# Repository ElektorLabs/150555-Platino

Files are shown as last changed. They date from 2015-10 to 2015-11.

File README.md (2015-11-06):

# 150555-Platino
Arduino compatible universal AVR board for 28-pin and 40-pin ATmega devices.

Platino is a board that address the ever returning problem of adding a user interface to a project. With 
Platino this is solved so that you can concentrate on your application instead of fiddling with low-level
drivers for user interfacing.

To achieve this Platino features footprints for pushbuttons, rotary encoders, a buzzer, an (RGB) LED, and an
LCD. Pushbuttons and rotary encoders have a flexible layout allowing a user interface adapted to the applications.
Platino supports 2 lines by 16 characters (2x16), 4x16 and 4x20 LCDs.

An Arduino library/core is available that contains drivers for all the peripherals, making programming easy.
Don't worry about debouncing pushbuttons, controlling LCDs or reading rotary encoders, the library handles it all
for you.

For even more flexibility Platino has solder jumpers to configure the board, allowing peripherals to be connected
to different ports.

Platino supports the following MCUs:
- ATmega8
- ATmega16
- ATmega32
- ATmega48 (not supported in Arduino IDE)
- ATmega88
- ATmega164
- ATmega168
- ATmega324
- ATmega328
- ATmega644
- ATmega1284

Arduino compatible bootloaders for all supported processors (except ATmega48) are available too.

For easy installation Platino is contained in a Board Package for the Arduino IDE, see https://github.com/ElektorLabs/Arduino

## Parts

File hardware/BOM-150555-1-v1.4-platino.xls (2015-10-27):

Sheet: BOM
BOM::150555::PLATINO::v1.4
Description | Manufacturer | Reference | Footprint | Designation | Qnt | Farnell | Digikey | RS
Resistor (5%, 0.25 W) |  |  |  |  | 13
47 Ω | Multicomp | MCF 0.25W 47R | ELPP-70-100 | R2, R3 | 2 | 9339523
470 Ω | Multicomp | MCF 0.25W 470R | ELPP-70-100 | R1, R8, R9 | 3 | 9339531
4.7 kΩ | Multicomp | MCF 0.25W 4K7 | ELPP-70-100 | R11 | 1 | 9339540
10 kΩ | Multicomp | MCF 0.25W 10K | ELPP-70-100 | R4, R5, R6, R7, R10, R12 | 6 | 9339060
Trimmer 10 kΩ, horizontal | TE Connectivity / Citec | CB10LV103M | ELPP-TRIMMER-CB10-H | P1 | 1 | 1227569
Capacitor |  |  |  |  | 7
22 pF, C0G, 50 V, 2.5 mm | Multicomp | MCCHU5220J5 | ELPP-CNP-250 | C1, C2 | 2 | 9411674
10 nF X7R, 100 V, 2.54 mm | Multicomp | MCRR50103X7RK0100 | ELPP-CNP-254 | C4 | 1 | 1216435
100 nF, Z5U, 50 V, 2.54 or 5.08 mm | Multicomp | MCRR50104Z5UM0050 | ELPP-CNP-508 | C3, C5, C6, C10 | 4 | 1216440
1 uF, 50 V, 2.5mm | Multicomp | NP35V105M5X11 | ELPP-CP-200-500 | C7, C8 | 2 | 9451358
10 uF, 50 V, 2.5 mm | Multicomp | NP35V106M5X11 | ELPP-CP-200-500 | C9 | 1 | 9451382
Inductor / Self |  |  |  |  | 1
10 µH | Bourns | 78F100J-RC | ELPP-L-70-100 | L1 | 1 | 1180270
Semiconductor |  |  |  |  | 6
1N5817 | Vishay | 1N5817 | ELPP-DO-41 | D2, D3 | 2 | 9801197
LED RGB, 5 mm | Kingbright | L-154A4SURKQBDZGW | LED RGB 5 mm | LED1 | 1 | 2290374
BC547C, 45 V, 100 mA, 500 mW, hfe=400 | ON Semiconductor | BC547CG | ELPP-TO-92 | T1 | 1 | 2101811
MC7805, 5 V, 1 A | ON Semiconductor | MC7805CTG | ELPP-TO-220-x | IC3 | 1 | 9666095
MCP1700-3302E/TO, LDO, 3.3 V, 0.25 A | Microchip | MCP1700-3302E/TO | ELPP-TO-92 | IC4 | 1 | 1296588
Misc.
IC socket DIP40 | Multicomp | 2227MC-40-06-05-F1 | ELPP-IC-SOCKET | IC1 | 1 | 1103855
IC socket DIP28, 7.62 mm (narrow) | Multicomp | 2227MC-28-03-05-F1 | ELPP-IC-SOCKET | IC2 | 1 | 1103850
16 MHz, 18 pF | Raltron | AS-16.000-18 | ELPP-HC49 | X1 | 1 | 1611761
Buzzer 12 mm | Pro Signal | ABT-410-RC | ELPP-BUZZER-12MM | BUZ1 | 1 | 1022402
Push button | Multimec | 3FTL6 | through-hole | S1, S2, S3, S4 | 4 | 1132885
Rotary encoder | Alps | EC12E2424407 | through-hole | SW1, SW2 | 2 | 1520813
header socket 10 pin, 0,1" pitch vertical | Fisher Elektronik | BL1.10Z | ELPP-SIL-F-10-WAY | K1 | 1 | 9728856
header male 6 pin, 0.1" pitch vertical | Fisher Elektronik | SL1.025.6Z | ELPP-SIL-M-6-WAY-90DEG | K2 | 1
header male 2x3 pin, 0.1" pitch vertical | Fisher Elektronik | SL2.025.6Z | ELPP-DIL-M-6-WAY-V | K3 | 1 | 9729070
header socket 8 pin, 0,1" pitch vertical | Fisher Elektronik | BL1.8Z | ELPP-SIL-F-8-WAY | K4, K5 | 2 | 9728856
header socket 6 pin, 0,1" pitch vertical | Fisher Elektronik | BL1.6Z | ELPP-SIL-F-6-WAY | K6, K7 | 2 | 9728856
header male 3 pin, 0.1" pitch vertical | Fisher Elektronik | SL1.025.3Z | ELPP-SIL-M-3-WAY | K8 | 1 | 9729038
header socket 16 pin, 0,1" pitch vertical | Fisher Elektronik | BL1.16Z | ELPP-SIL-F-16-WAY | K9 | 1 | 9728856
Terminal block 3.5 mm, 2-way, 250 V | TE Connectivity | 1776275-2 | ELPP-TB-350-2 | K12 | 1 | 1098611
 |  |  |  | K10, K11
LCD 2x16
LCD 4x20

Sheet: history
DOCUMENT HISTORY
Date | Rev. | Author | Description

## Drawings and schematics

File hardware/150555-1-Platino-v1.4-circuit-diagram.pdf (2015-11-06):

## CONFIGURE SOLDER JUMPERS FIRST

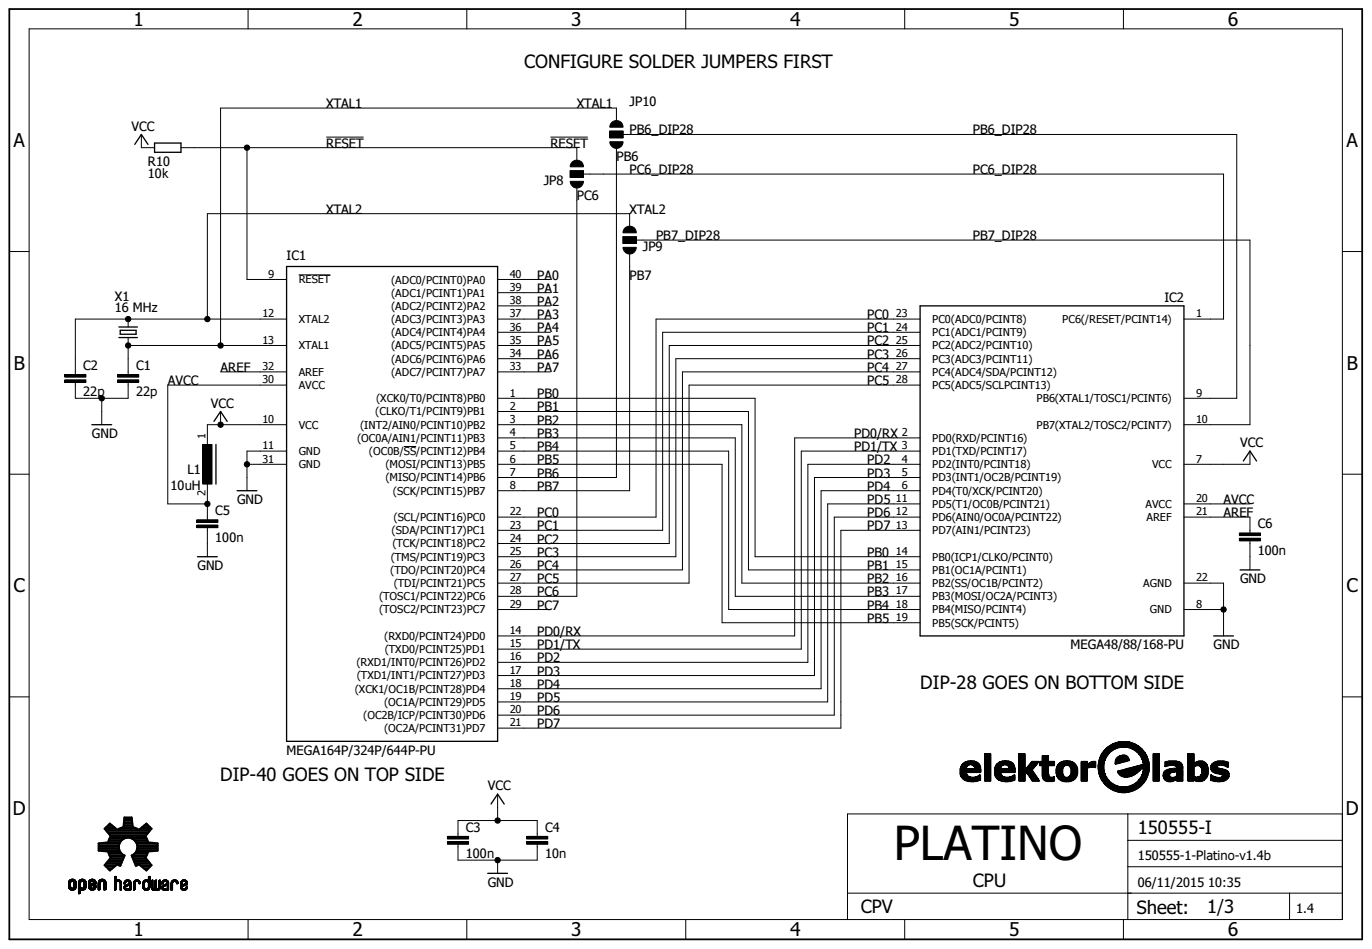
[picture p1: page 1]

DIP-28 GOES ON BOTTOM SIDE

DIP-40 GOES ON TOP SIDE

## CONFIGURE SOLDER JUMPERS FIRST

## Ex = Encoder x LCD_20X4

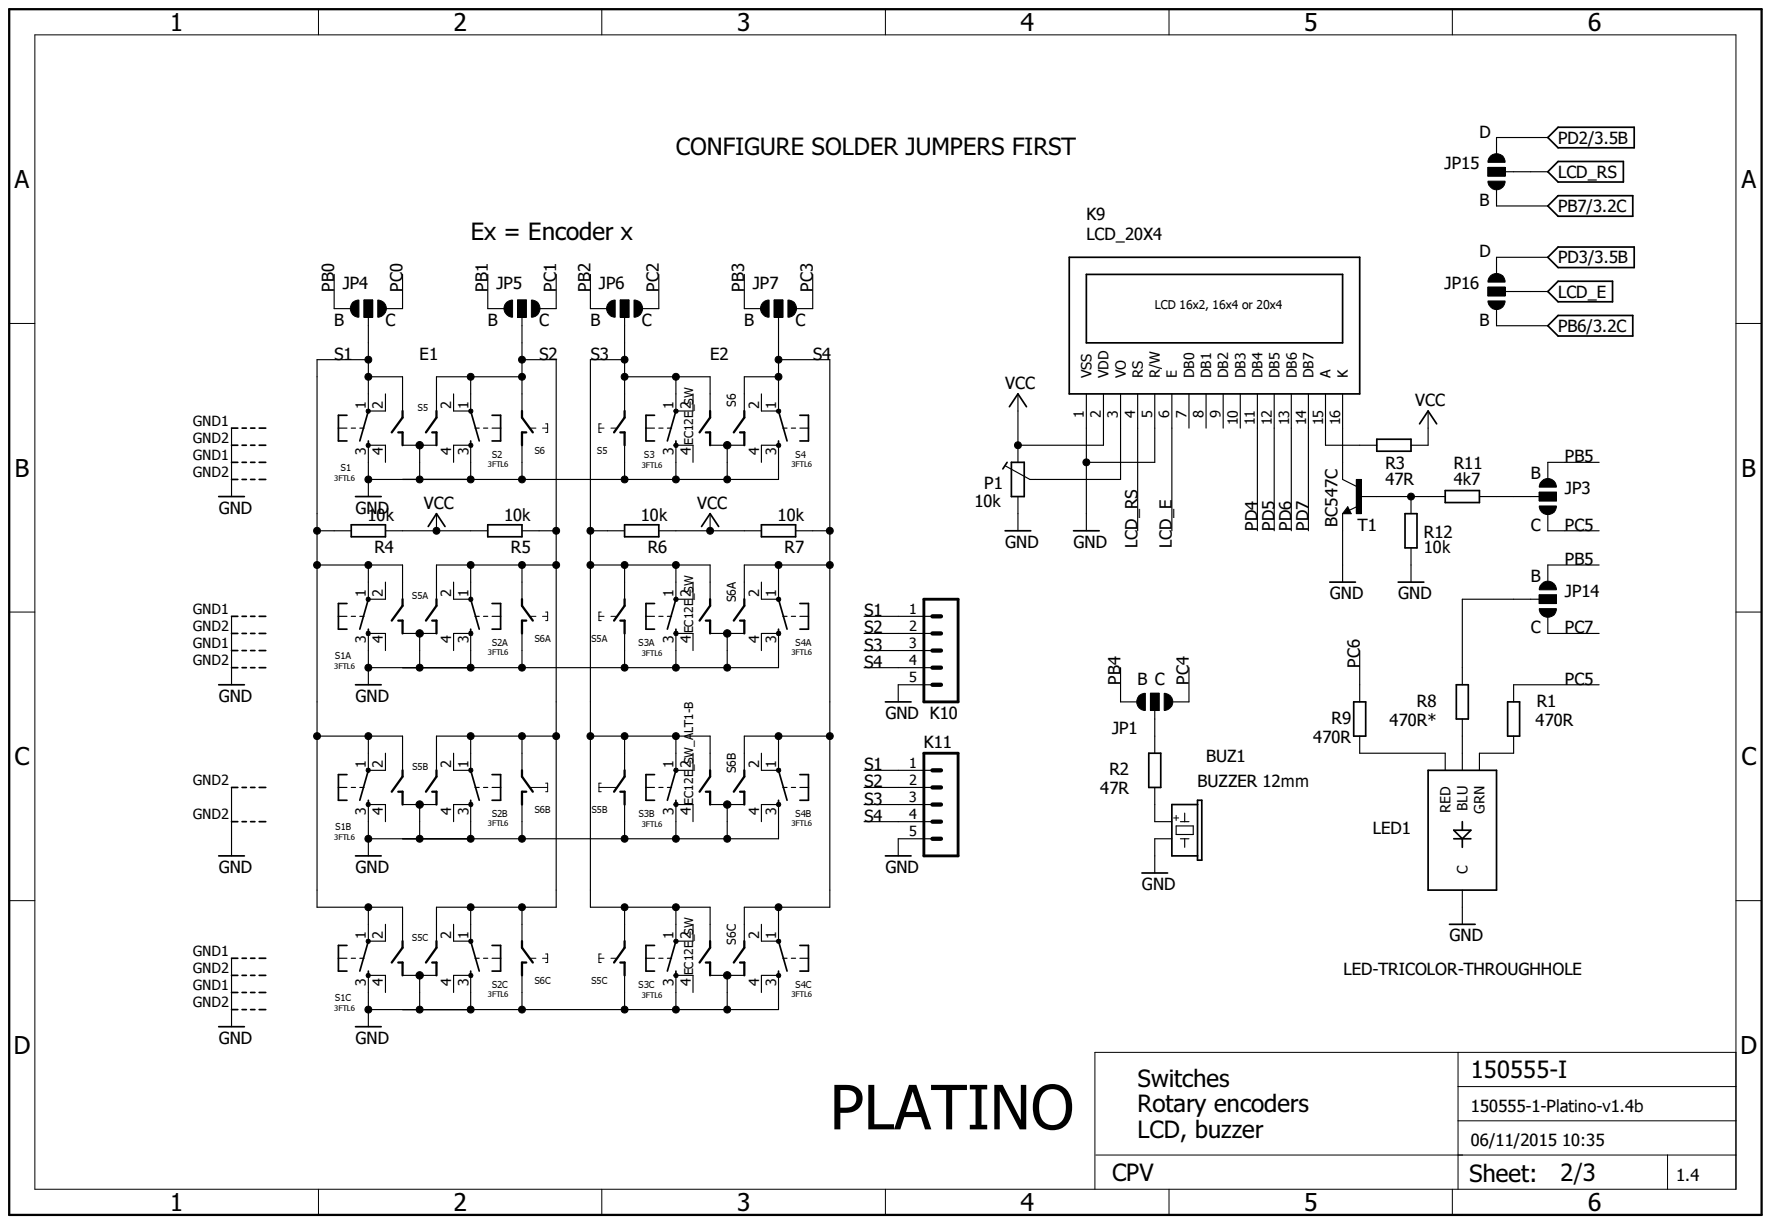
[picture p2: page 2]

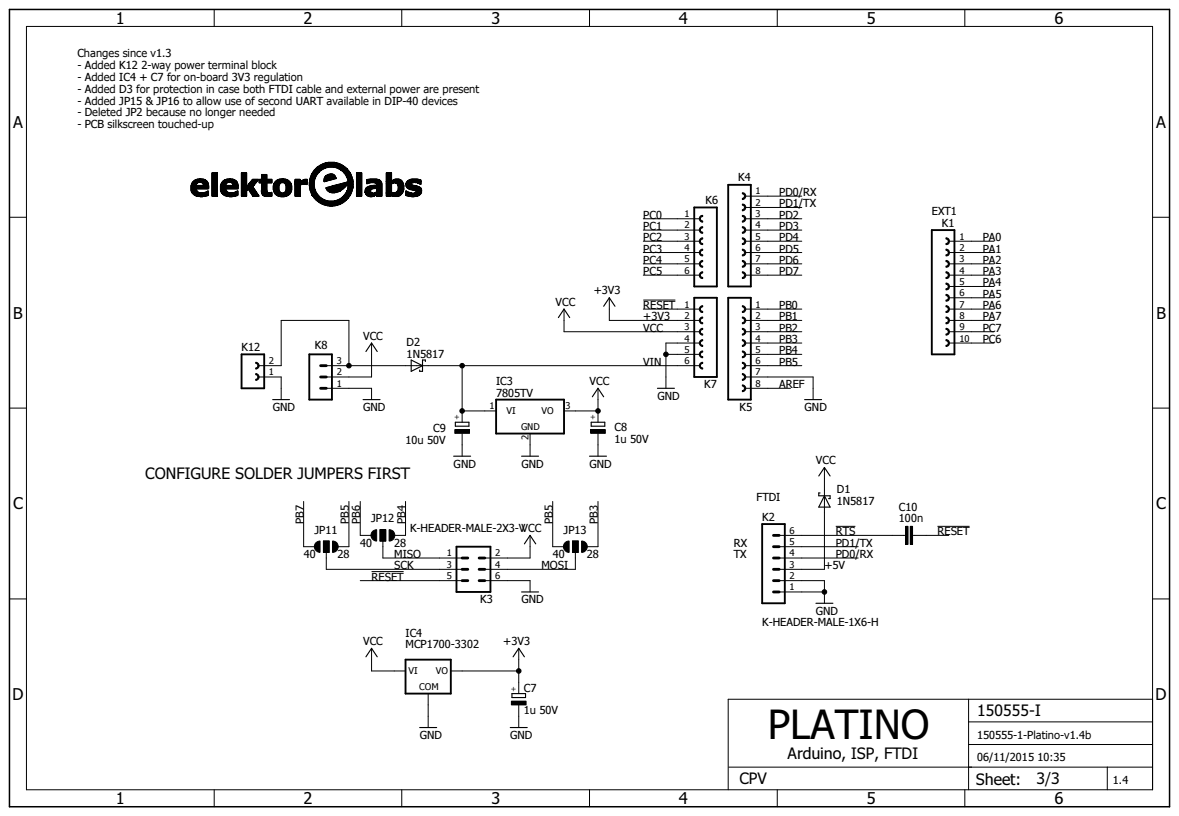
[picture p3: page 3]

Changes since v1.3
- Added K12 2-way power terminal block
- Added IC4 + C7 for on-board 3V3 regulation
- Added D3 for protection in case both FTDI cable and external power are present
- Added JP15 & JP16 to allow use of second UART available in DIP-40 devices
- Deleted JP2 because no longer needed
- PCB silkscreen touched-up

CONFIGURE SOLDER JUMPERS FIRST

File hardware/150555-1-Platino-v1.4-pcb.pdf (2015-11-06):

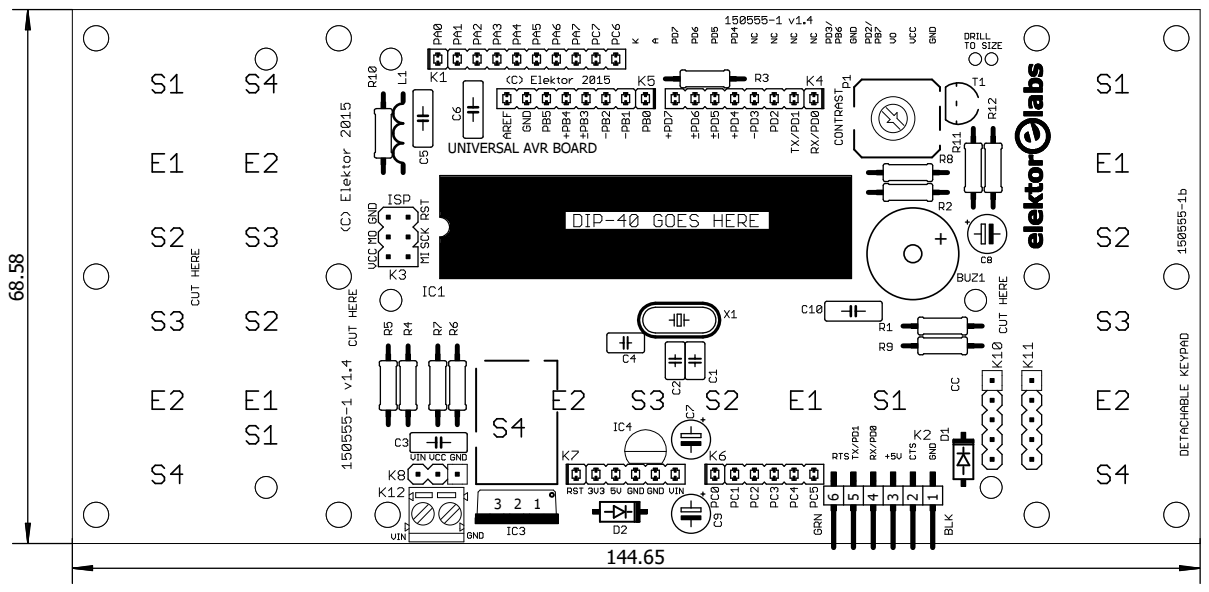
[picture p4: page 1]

UNIVERSAL AVR BOARD

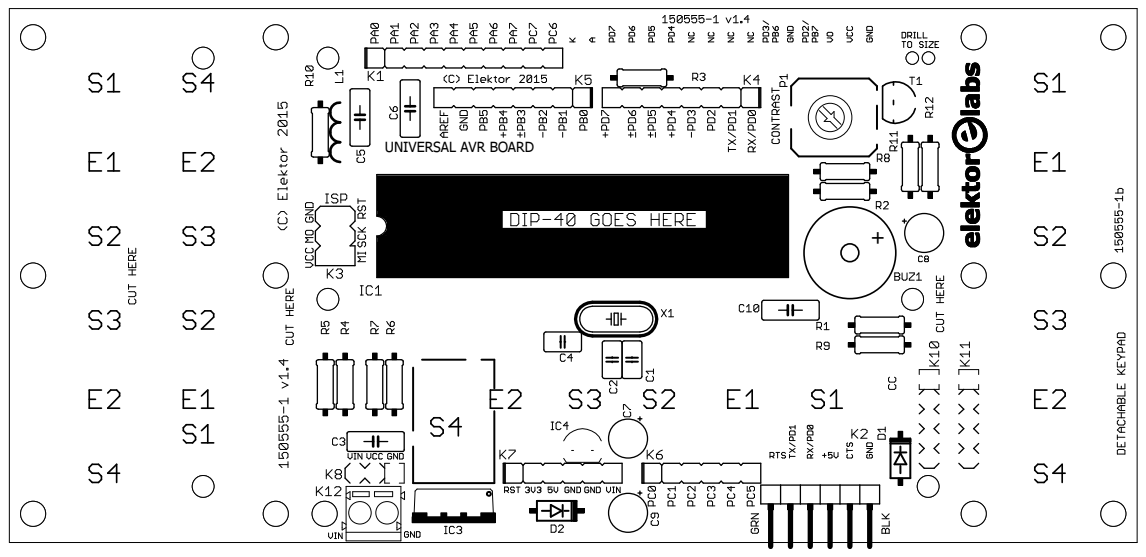
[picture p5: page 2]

UNIVERSAL AVR BOARD

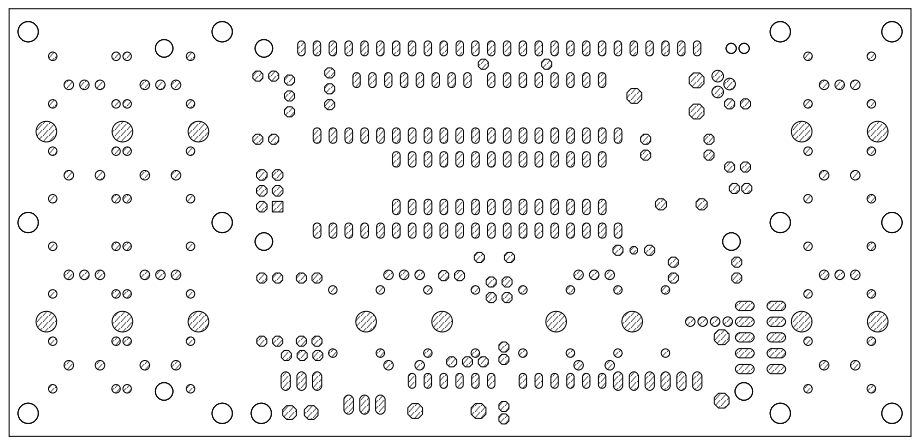
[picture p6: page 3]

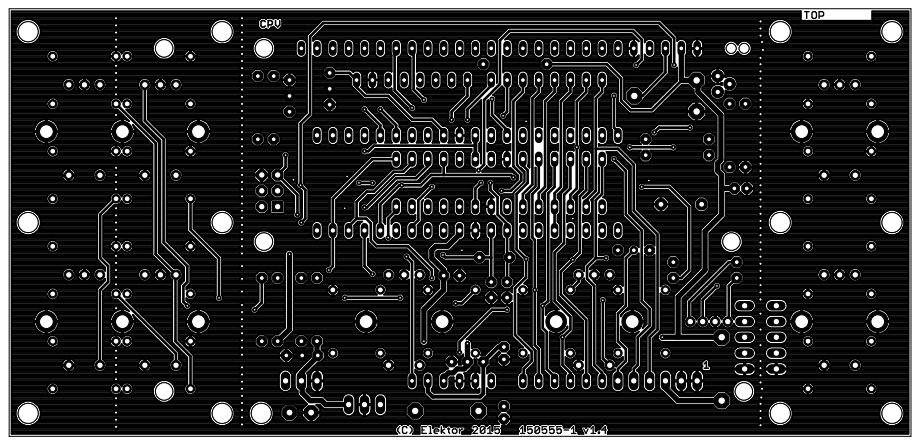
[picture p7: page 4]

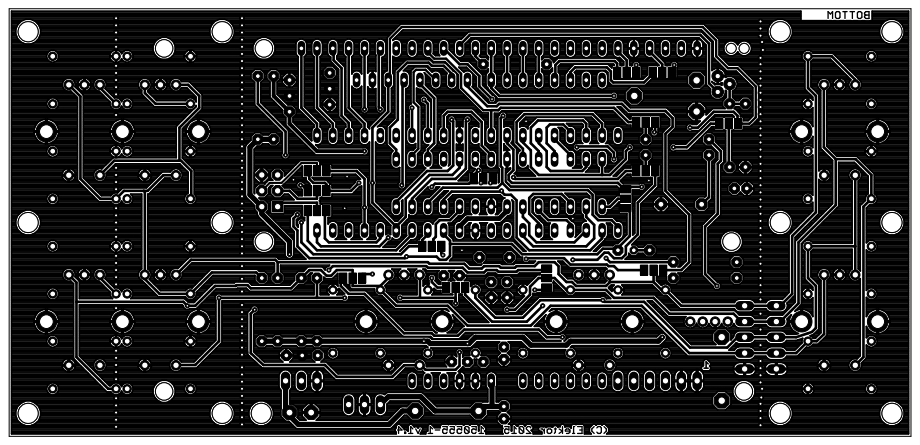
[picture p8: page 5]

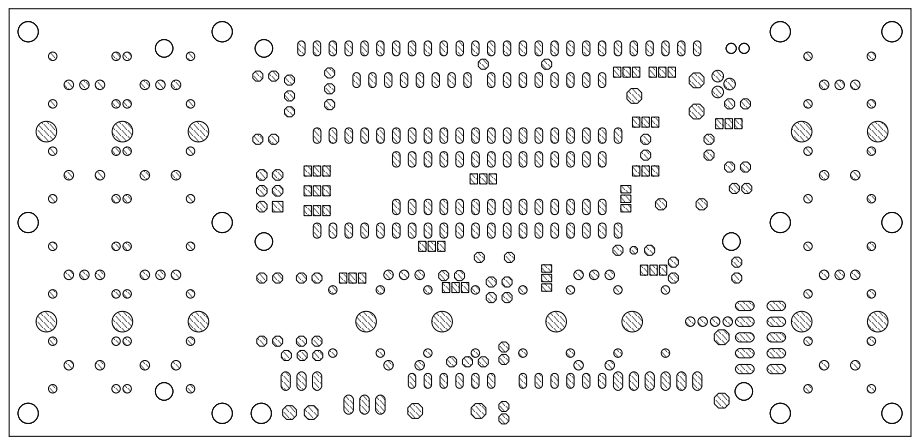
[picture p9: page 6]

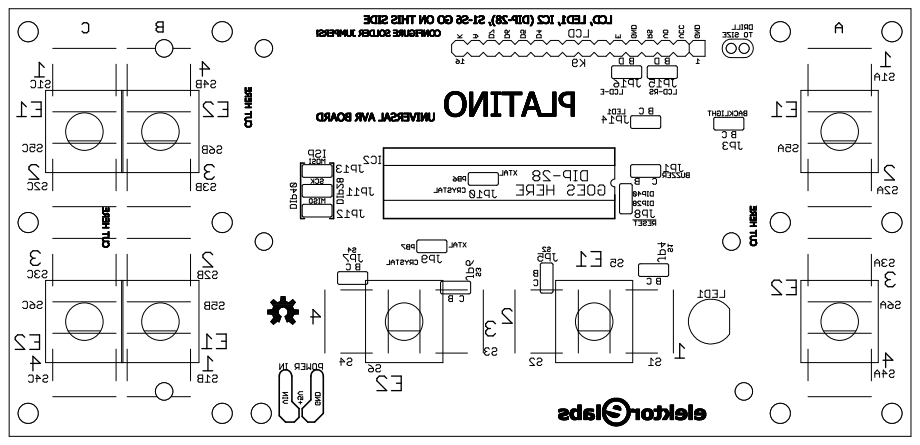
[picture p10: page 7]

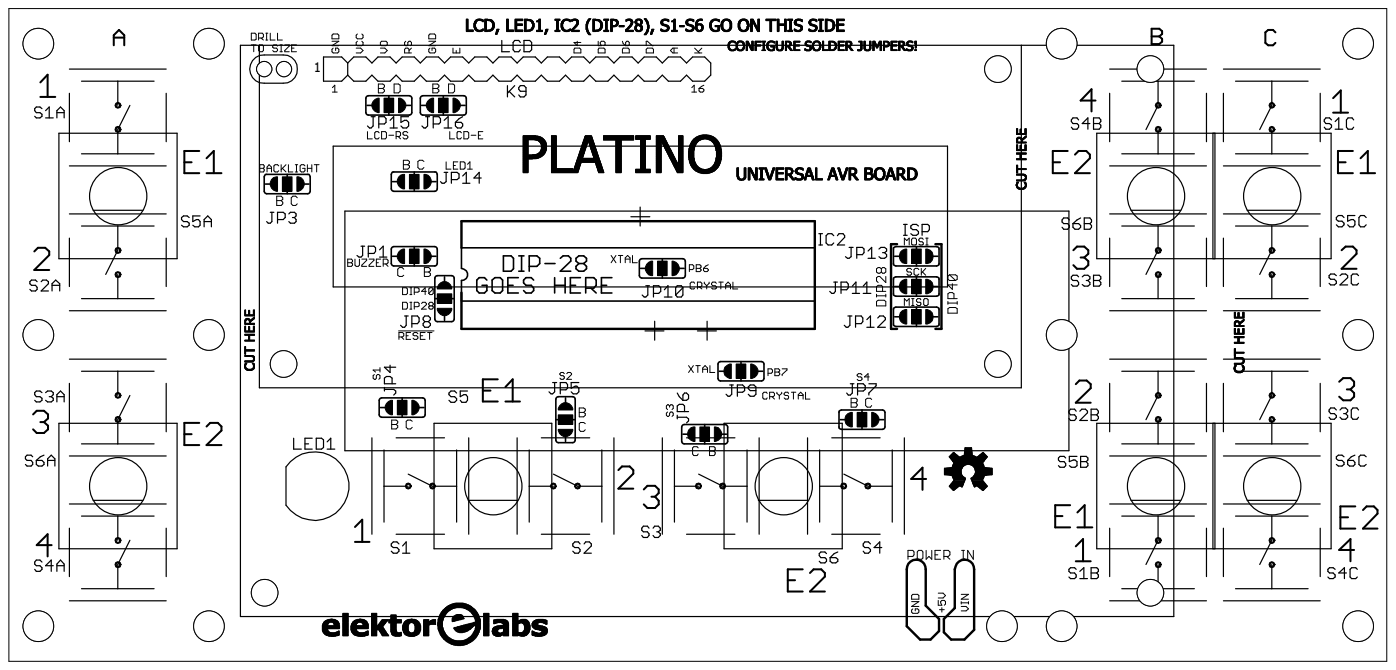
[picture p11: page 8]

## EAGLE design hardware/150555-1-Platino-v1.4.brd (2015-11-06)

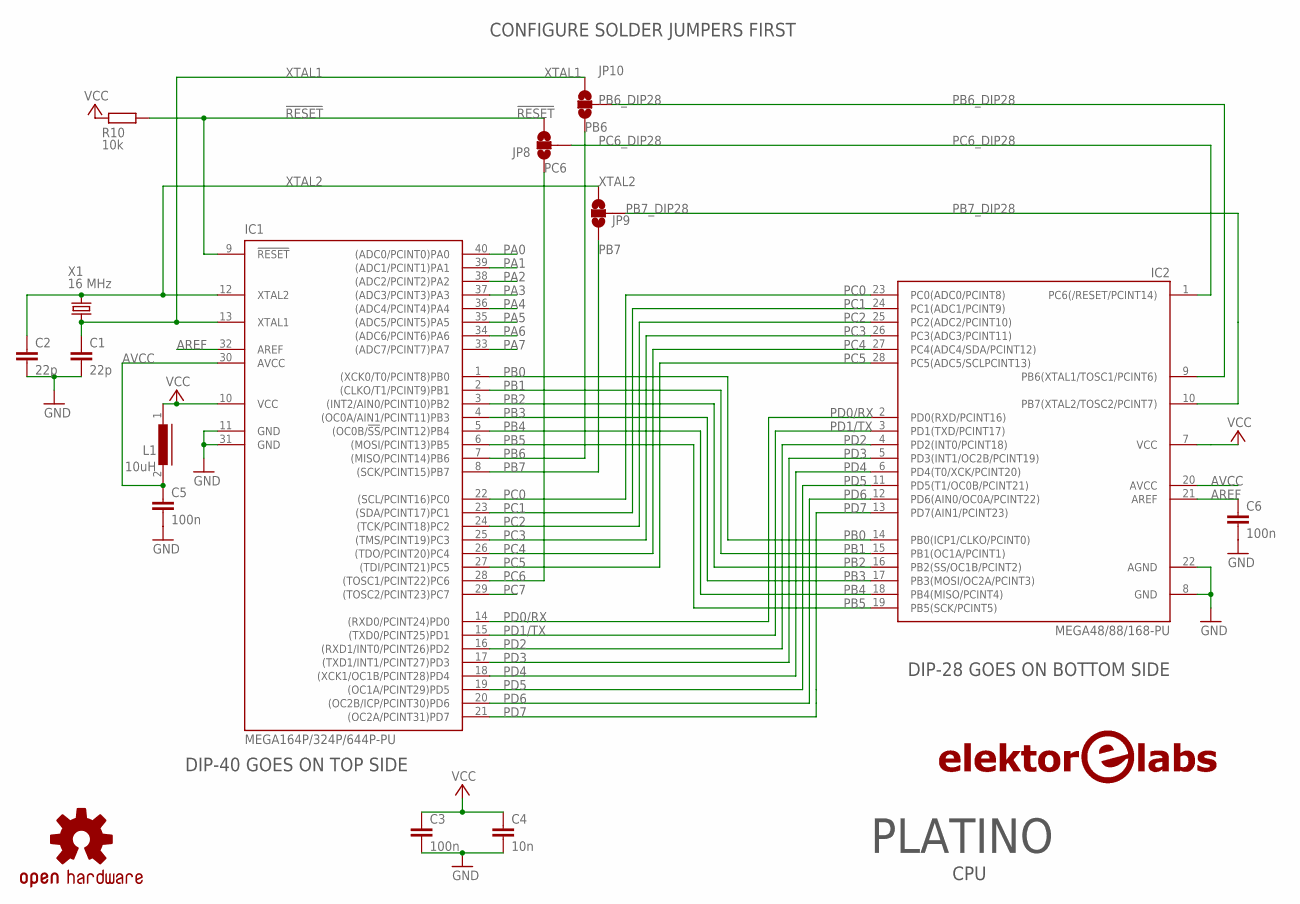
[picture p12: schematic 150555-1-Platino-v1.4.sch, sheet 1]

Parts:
C1, C2: 22p; ELPP-CNP-250
C3, C5, C6: 100n; ELPP-CNP-508
C4: 10n; ELPP-CNP-254
IC1: MEGA164P/324P/644P-PU; DIL40
IC2: MEGA48/88/168-PU; DIL28-3
JP8, JP9, JP10: SOLDERJUMPER_2WAYT; SJ_2
L1: 10uH; ELPP-L-0207-1000
LOGO2: LOGO-ELEKTOR-LABS-25MM; EPP-LOGO-ELEKTOR-LABS-25MM
R10: 10k; ELPP-R-0207-1000
U$2: OSHW-LOGOM; OSHW-LOGO-M
X1: 16 MHz; ELPP-HC49

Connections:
!RESET: IC1.9 (!RESET), JP8.3, R10.1; also elsewhere on the board
AREF: C6.1, IC1.32 (AREF), IC2.21 (AREF); also elsewhere on the board
AVCC: C5.1, IC1.30 (AVCC), IC2.20 (AVCC), L1.2
GND: C1.2, C2.2, C3.2, C4.2, C5.2, C6.2, IC1.11 (GND), IC1.31 (GND), IC2.8 (GND), IC2.22 (AGND); also elsewhere on the board
PA0: IC1.40 ((ADC0/PCINT0)PA0); also elsewhere on the board
PA1: IC1.39 ((ADC1/PCINT1)PA1); also elsewhere on the board
PA2: IC1.38 ((ADC2/PCINT2)PA2); also elsewhere on the board
PA3: IC1.37 ((ADC3/PCINT3)PA3); also elsewhere on the board
PA4: IC1.36 ((ADC4/PCINT4)PA4); also elsewhere on the board
PA5: IC1.35 ((ADC5/PCINT5)PA5); also elsewhere on the board
PA6: IC1.34 ((ADC6/PCINT6)PA6); also elsewhere on the board
PA7: IC1.33 ((ADC7/PCINT7)PA7); also elsewhere on the board
PB0: IC1.1 ((XCK0/T0/PCINT8)PB0), IC2.14 (PB0(ICP1/CLKO/PCINT0)); also elsewhere on the board
PB1: IC1.2 ((CLKO/T1/PCINT9)PB1), IC2.15 (PB1(OC1A/PCINT1)); also elsewhere on the board
PB2: IC1.3 ((INT2/AIN0/PCINT10)PB2), IC2.16 (PB2(SS/OC1B/PCINT2)); also elsewhere on the board
PB3: IC1.4 ((OC0A/AIN1/PCINT11)PB3), IC2.17 (PB3(MOSI/OC2A/PCINT3)); also elsewhere on the board
PB4: IC1.5 ((OC0B/!SS!/PCINT12)PB4), IC2.18 (PB4(MISO/PCINT4)); also elsewhere on the board
PB5: IC1.6 ((MOSI/PCINT13)PB5), IC2.19 (PB5(SCK/PCINT5)); also elsewhere on the board
PB6: IC1.7 ((MISO/PCINT14)PB6), JP10.1; also elsewhere on the board
PB6_DIP28: IC2.9 (PB6(XTAL1/TOSC1/PCINT6)), JP10.2
PB7: IC1.8 ((SCK/PCINT15)PB7), JP9.1; also elsewhere on the board
PB7_DIP28: IC2.10 (PB7(XTAL2/TOSC2/PCINT7)), JP9.2
PC0: IC1.22 ((SCL/PCINT16)PC0), IC2.23 (PC0(ADC0/PCINT8)); also elsewhere on the board
PC1: IC1.23 ((SDA/PCINT17)PC1), IC2.24 (PC1(ADC1/PCINT9)); also elsewhere on the board
PC2: IC1.24 ((TCK/PCINT18)PC2), IC2.25 (PC2(ADC2/PCINT10)); also elsewhere on the board
PC3: IC1.25 ((TMS/PCINT19)PC3), IC2.26 (PC3(ADC3/PCINT11)); also elsewhere on the board
PC4: IC1.26 ((TDO/PCINT20)PC4), IC2.27 (PC4(ADC4/SDA/PCINT12)); also elsewhere on the board
PC5: IC1.27 ((TDI/PCINT21)PC5), IC2.28 (PC5(ADC5/SCLPCINT13)); also elsewhere on the board
PC6: IC1.28 ((TOSC1/PCINT22)PC6), JP8.1; also elsewhere on the board
PC6_DIP28: IC2.1 (PC6(/RESET/PCINT14)), JP8.2
PC7: IC1.29 ((TOSC2/PCINT23)PC7); also elsewhere on the board
PD0/RX: IC1.14 ((RXD0/PCINT24)PD0), IC2.2 (PD0(RXD/PCINT16)); also elsewhere on the board
PD1/TX: IC1.15 ((TXD0/PCINT25)PD1), IC2.3 (PD1(TXD/PCINT17)); also elsewhere on the board
PD2: IC1.16 ((RXD1/INT0/PCINT26)PD2), IC2.4 (PD2(INT0/PCINT18)); also elsewhere on the board
PD3: IC1.17 ((TXD1/INT1/PCINT27)PD3), IC2.5 (PD3(INT1/OC2B/PCINT19)); also elsewhere on the board
PD4: IC1.18 ((XCK1/OC1B/PCINT28)PD4), IC2.6 (PD4(T0/XCK/PCINT20)); also elsewhere on the board
PD5: IC1.19 ((OC1A/PCINT29)PD5), IC2.11 (PD5(T1/OC0B/PCINT21)); also elsewhere on the board
PD6: IC1.20 ((OC2B/ICP/PCINT30)PD6), IC2.12 (PD6(AIN0/OC0A/PCINT22)); also elsewhere on the board
PD7: IC1.21 ((OC2A/PCINT31)PD7), IC2.13 (PD7(AIN1/PCINT23)); also elsewhere on the board
VCC: C3.1, C4.1, IC1.10 (VCC), IC2.7 (VCC), L1.1, R10.2; also elsewhere on the board
XTAL1: C1.1, IC1.13 (XTAL1), JP10.3, X1.1
XTAL2: C2.1, IC1.12 (XTAL2), JP9.3, X1.2

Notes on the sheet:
CPU
CONFIGURE SOLDER JUMPERS FIRST
DIP-40 GOES ON TOP SIDE
DIP-28 GOES ON BOTTOM SIDE
PLATINO

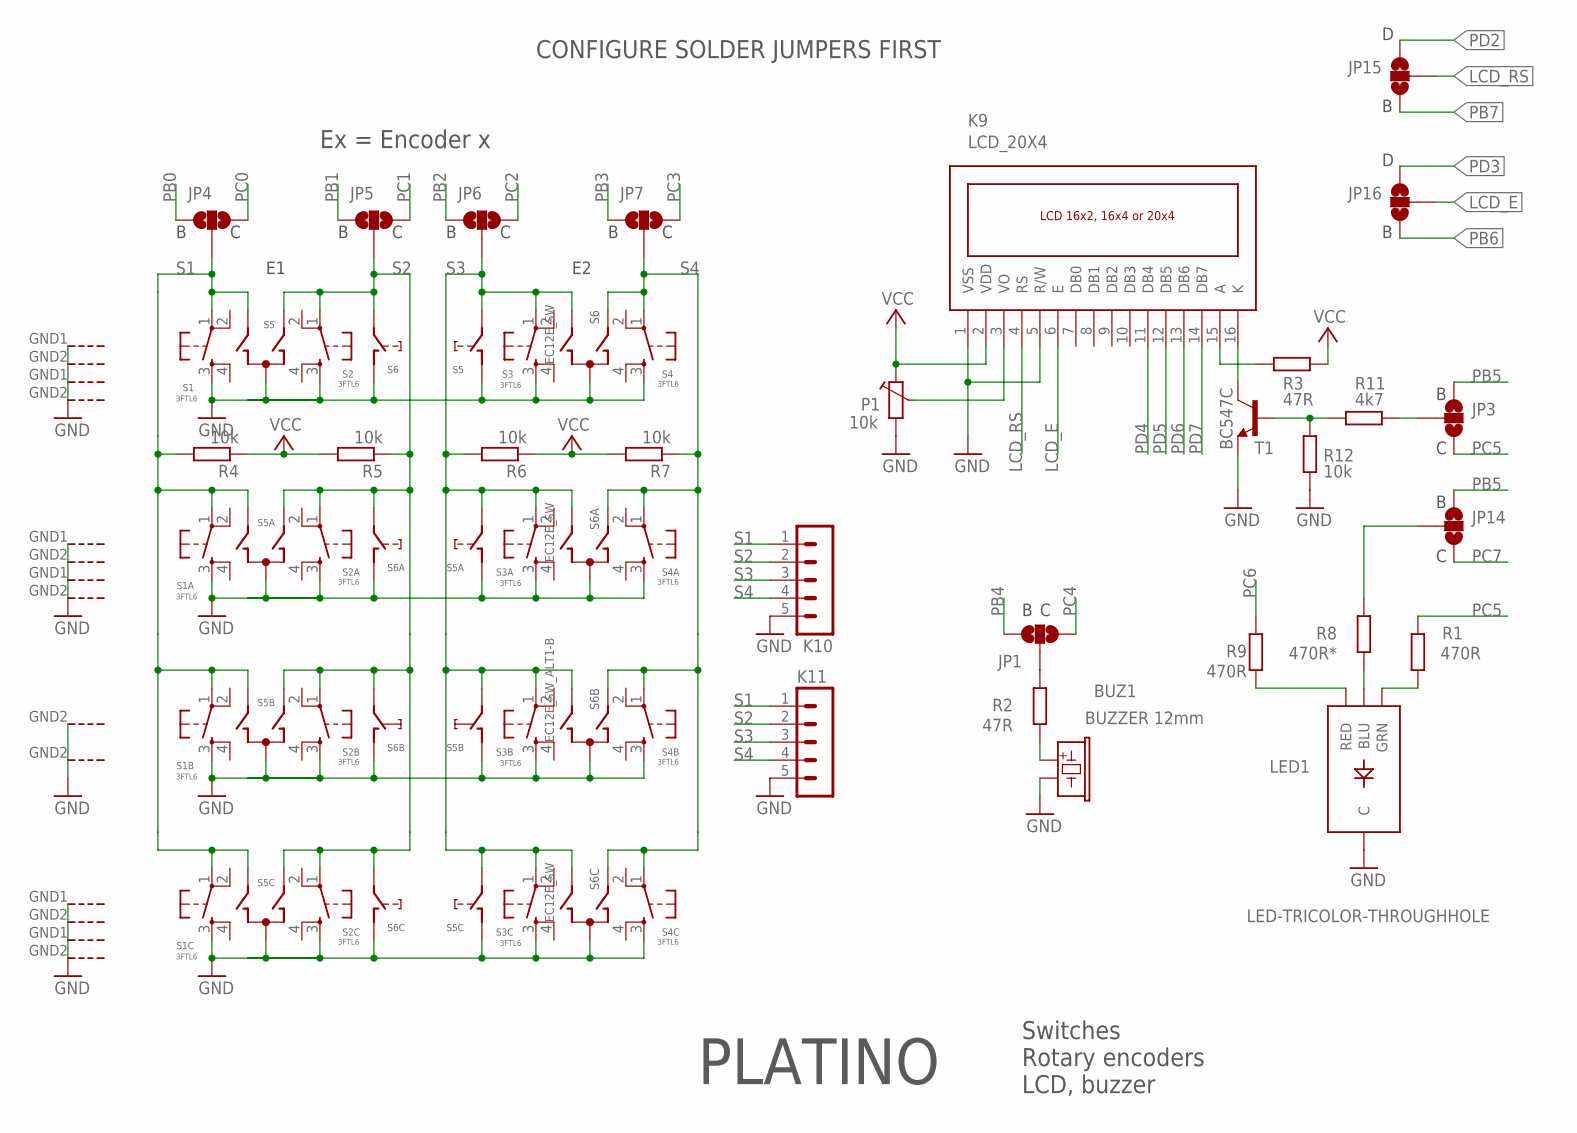
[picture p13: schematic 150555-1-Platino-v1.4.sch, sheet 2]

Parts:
BUZ1: BUZZER 12mm; ELPP-BUZZER-12MM
JP1, JP3, JP4, JP5, JP6, JP7, JP14, JP15, JP16: SOLDERJUMPER_2WAYT; SJ_2
K9: LCD_20X4; LCD_MULTI2
K10, K11: K-HEADER-MALE-1X5-V; ELPP-SIL-M-5-WAY
LED1: LED-TRICOLOR-THROUGHHOLE
P1: 10k; ELPP-TRIMMER-CB10-H
R1, R9: 470R; ELPP-R-0207-1000
R2, R3: 47R; ELPP-R-0207-1000
R4, R5, R6, R7, R12: 10k; ELPP-R-0207-1000
R8: 470R*; ELPP-R-0207-1000
R11: 4k7; ELPP-R-0207-1000
S1, S1A, S1B, S1C, S2, S2A, S2B, S2C, S3, S3A, S3B, S3C, S4, S4A, S4B, S4C: 3FTL6; PUSHBUTTON_MULTIMEC
S5, S5A, S5C, S6, S6A, S6C: EC12E_SW; ALPS_EC12E_SW
S5B, S6B: EC12E_SW_ALT1-B; ALPS_EC12E_SW_ALT2
T1: BC547C; TO-92

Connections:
BLUE: LED1.BLU, R8.1
GATE: JP3.2, R11.2
GND: BUZ1.- (2), K9.1 (VSS), K9.5 (R/W), K10.5, K11.5, LED1.GND (C), P1.1, R12.1, S1.3, S1A.3, S1B.3, S1C.3, S2.3, S2A.3, S2B.3, S2C.3, S3.3, S3A.3, S3B.3, S3C.3, S4.3, S4A.3, S4B.3, S4C.3, S5.C, S5.D (1), S5.GND1 (G), S5.GND2 (G), S5A.C, S5A.D (1), S5A.GND1 (G), S5A.GND2 (G), S5B.C, S5B.D (1), S5B.GND2 (G), S5C.C, S5C.D (1), S5C.GND1 (G), S5C.GND2 (G), S6.C, S6.D (1), S6.GND1 (G), S6.GND2 (G), S6A.C, S6A.D (1), S6A.GND1 (G), S6A.GND2 (G), S6B.C, S6B.D (1), S6B.GND2 (G), S6C.C, S6C.D (1), S6C.GND1 (G), S6C.GND2 (G), T1.1 (E); also elsewhere on the board
GREEN: LED1.GRN, R1.1
LCD_BL_A: K9.15 (A), R3.1
LCD_BL_K: K9.16 (K), T1.3 (C)
LCD_E: JP16.2, K9.6 (E)
LCD_RS: JP15.2, K9.4 (RS)
LCD_VO: K9.3 (VO), P1.3
unnamed: BUZ1.+ (1), R2.1
unnamed: R11.1, R12.2, T1.2 (B)
unnamed: JP1.2, R2.2
unnamed: JP14.2, R8.2
PB0: JP4.1; also elsewhere on the board
PB1: JP5.1; also elsewhere on the board
PB2: JP6.1; also elsewhere on the board
PB3: JP7.1; also elsewhere on the board
PB4: JP1.1; also elsewhere on the board
PB5: JP3.3, JP14.3; also elsewhere on the board
PB6: JP16.1; also elsewhere on the board
PB7: JP15.1; also elsewhere on the board
PC0: JP4.3; also elsewhere on the board
PC1: JP5.3; also elsewhere on the board
PC2: JP6.3; also elsewhere on the board
PC3: JP7.3; also elsewhere on the board
PC4: JP1.3; also elsewhere on the board
PC5: JP3.1, R1.2; also elsewhere on the board
PC6: R9.2; also elsewhere on the board
PC7: JP14.1; also elsewhere on the board
PD2: JP15.3; also elsewhere on the board
PD3: JP16.3; also elsewhere on the board
PD4: K9.11 (DB4); also elsewhere on the board
PD5: K9.12 (DB5); also elsewhere on the board
PD6: K9.13 (DB6); also elsewhere on the board
PD7: K9.14 (DB7); also elsewhere on the board
RED: LED1.RED, R9.1
S1: JP4.2, K10.1, K11.1, R4.2, S1.1, S1A.1, S1B.1, S1C.1, S5.B, S5A.B, S5B.B, S5C.B
S2: JP5.2, K10.2, K11.2, R5.1, S2.1, S2A.1, S2B.1, S2C.1, S5.A, S5A.A, S5B.A, S5C.A, S6.E (2), S6A.E (2), S6B.E (2), S6C.E (2)
S3: JP6.2, K10.3, K11.3, R6.2, S3.1, S3A.1, S3B.1, S3C.1, S5.E (2), S5A.E (2), S5B.E (2), S5C.E (2), S6.B, S6A.B, S6B.B, S6C.B
S4: JP7.2, K10.4, K11.4, R7.1, S4.1, S4A.1, S4B.1, S4C.1, S6.A, S6A.A, S6B.A, S6C.A
VCC: K9.2 (VDD), P1.2, R3.2, R4.1, R5.2, R6.1, R7.2; also elsewhere on the board

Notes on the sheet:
Switches
Rotary encoders
LCD, buzzer
CONFIGURE SOLDER JUMPERS FIRST
PLATINO
Ex = Encoder x

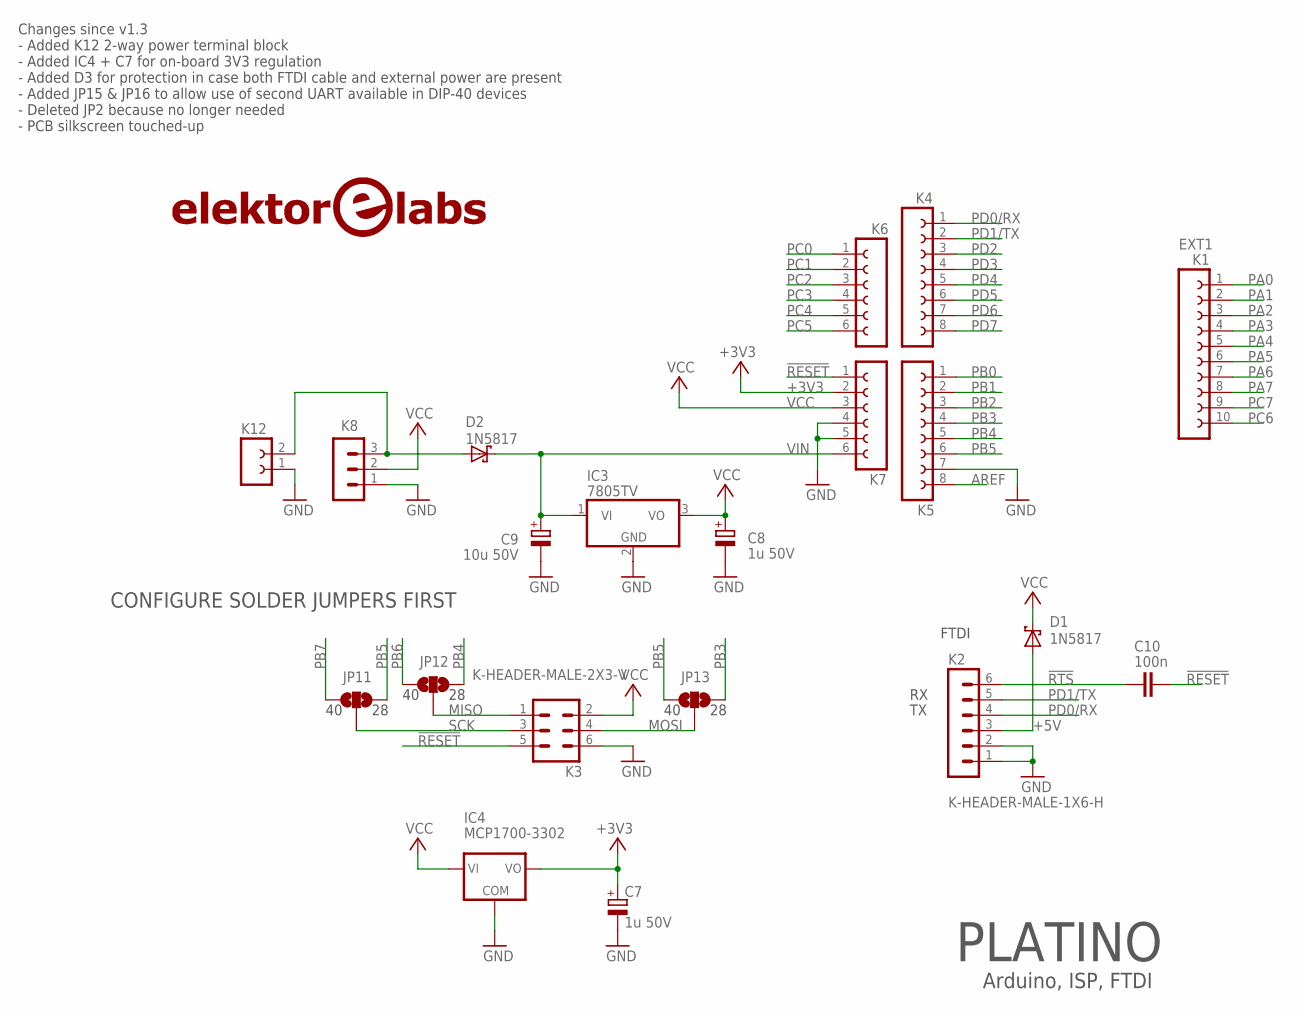
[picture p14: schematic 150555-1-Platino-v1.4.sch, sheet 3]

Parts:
C7, C8: 1u 50V; ELPP-CP-200-500
C9: 10u 50V; ELPP-CP-200-500
C10: 100n; ELPP-CNP-508
D1, D2: 1N5817; ELPP-DO-41
IC3: 7805TV; TO220V
IC4: MCP1700-3302; ELPP-TO-92
JP11, JP12, JP13: SOLDERJUMPER_2WAYT; SJ_2
K1: EXT1; ELPP-SIL-F-10-WAY
K2: K-HEADER-MALE-1X6-H; ELPP-SIL-M-6-WAY-90DEG
K3: K-HEADER-MALE-2X3-V; ELPP-DIL-M-6-WAY-V
K4, K5: K-HEADER-FEMALE-1X8-V; ELPP-SIL-F-8-WAY
K6, K7: K-HEADER-FEMALE-1X6-V; ELPP-SIL-F-6-WAY
K8: K-HEADER-MALE-1X3-V; ELPP-SIL-M-3-WAY
K12: K-TERMINAL-BLOCK-1X2-350; ELPP-TB-350-2
LOGO1: LOGO-ELEKTOR-LABS-25MM; EPP-LOGO-ELEKTOR-LABS-25MM

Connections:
!RESET: C10.2, K3.5, K7.1; also elsewhere on the board
!RTS: C10.1, K2.6
+3V3: C7.+, IC4.3 (VO), K7.2
+5V: D1.A, K2.3
AREF: K5.8; also elsewhere on the board
GND: C7.-, C8.-, C9.-, IC3.2 (GND), IC4.1 (COM), K2.1, K2.2, K3.6, K5.7, K7.4, K7.5, K8.1, K12.1; also elsewhere on the board
MISO: JP12.2, K3.1
MOSI: JP13.2, K3.4
unnamed: D2.A, K8.3, K12.2
PA0: K1.1; also elsewhere on the board
PA1: K1.2; also elsewhere on the board
PA2: K1.3; also elsewhere on the board
PA3: K1.4; also elsewhere on the board
PA4: K1.5; also elsewhere on the board
PA5: K1.6; also elsewhere on the board
PA6: K1.7; also elsewhere on the board
PA7: K1.8; also elsewhere on the board
PB0: K5.1; also elsewhere on the board
PB1: K5.2; also elsewhere on the board
PB2: K5.3; also elsewhere on the board
PB3: JP13.3, K5.4; also elsewhere on the board
PB4: JP12.3, K5.5; also elsewhere on the board
PB5: JP11.3, JP13.1, K5.6; also elsewhere on the board
PB6: JP12.1; also elsewhere on the board
PB7: JP11.1; also elsewhere on the board
PC0: K6.1; also elsewhere on the board
PC1: K6.2; also elsewhere on the board
PC2: K6.3; also elsewhere on the board
PC3: K6.4; also elsewhere on the board
PC4: K6.5; also elsewhere on the board
PC5: K6.6; also elsewhere on the board
PC6: K1.10; also elsewhere on the board
PC7: K1.9; also elsewhere on the board
PD0/RX: K2.4, K4.1; also elsewhere on the board
PD1/TX: K2.5, K4.2; also elsewhere on the board
PD2: K4.3; also elsewhere on the board
PD3: K4.4; also elsewhere on the board
PD4: K4.5; also elsewhere on the board
PD5: K4.6; also elsewhere on the board
PD6: K4.7; also elsewhere on the board
PD7: K4.8; also elsewhere on the board
SCK: JP11.2, K3.3
VCC: C8.+, D1.C, IC3.3 (VO), IC4.2 (VI), K3.2, K7.3, K8.2; also elsewhere on the board
VIN: C9.+, D2.C, IC3.1 (VI), K7.6

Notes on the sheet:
Arduino, ISP, FTDI
FTDI
CONFIGURE SOLDER JUMPERS FIRST
PLATINO
Changes since v1.3 - Added K12 2-way power terminal block - Added IC4 + C7 for on-board 3V3 regulation - Added D3 for protection in case both FTDI cable and external power are present - Added JP15 & JP16 to allow use of second UART available in DIP-40 devices - Deleted JP2 because no longer needed 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

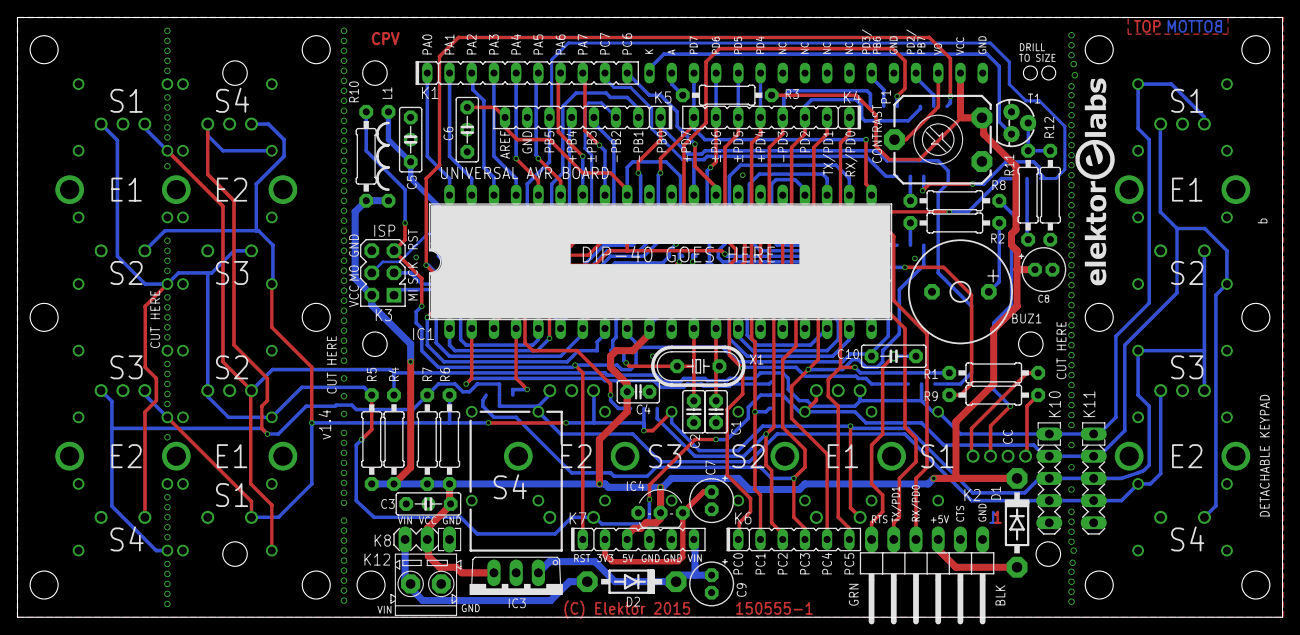
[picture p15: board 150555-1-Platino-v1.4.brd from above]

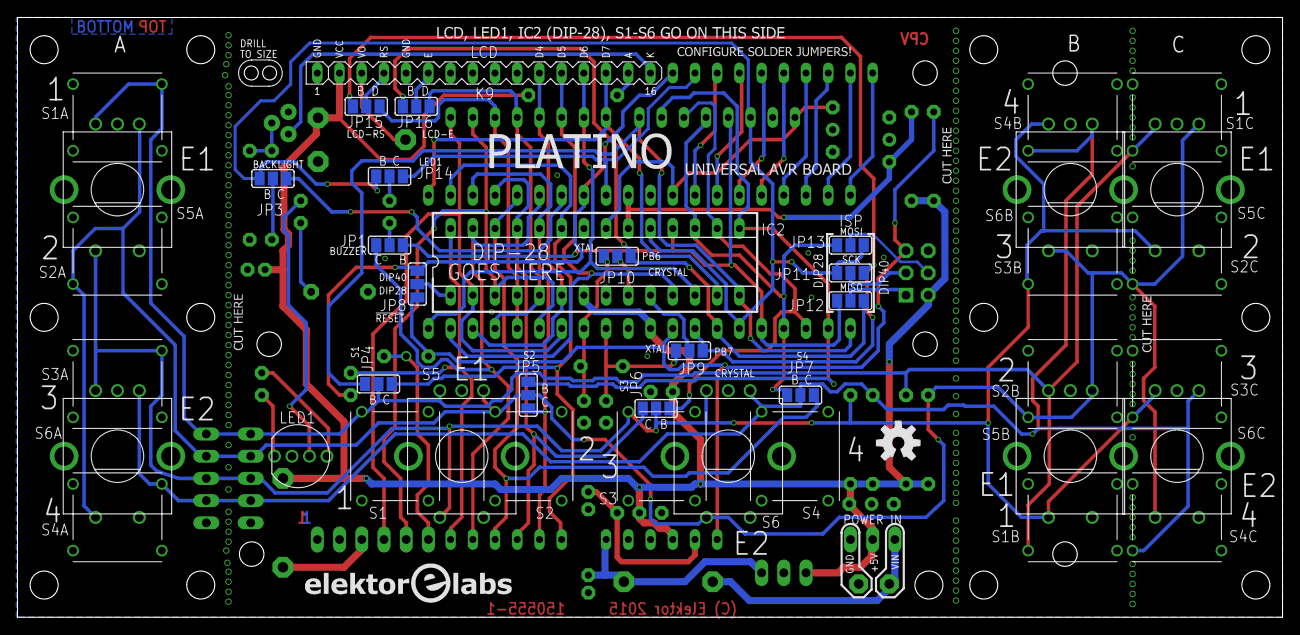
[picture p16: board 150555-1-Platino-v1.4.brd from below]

Board: 2 copper layers, 144.7 x 68.6 mm, 88 parts (44 on the bottom side), 67 nets.

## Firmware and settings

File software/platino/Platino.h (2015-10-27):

/*
  Platino.cpp - drivers for Platino.

  Copyright (c) 2011, 2015 Clemens Valens

  12/10/2015 - CPV, Support added for jumpers JP15 and JP16.
  03/02/2012 - CPV, Initials release.
  
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
*/

#ifndef __PLATINO_H__
#define __PLATINO_H__


/*
Definitions for Platino.

Solder jumpers
--------------
 JP1: Buzzer,         'B'=PB4, 'C'=PC4, 0=Open
 JP3: LCD backlight,  'B'=PB5, 'C'=PC5, 0=Open
 JP4: S1,             'B'=PB0, 'C'=PC0, 0=Open
 JP5: S2,             'B'=PB1, 'C'=PC1, 0=Open
 JP6: S3,             'B'=PB2, 'C'=PC2, 0=Open
 JP7: S4,             'B'=PB3, 'C'=PC3, 0=Open
JP14: RGB LED 2,      'B'=PB5, 'C'=PC7, 0=Open

New on revision 1.4 (150555-1)
JP15: LCD RS          'B'=PB7, 'D'=PD2', 0=Open
JP16: LCD E(nable)    'B'=PB6, 'D'=PD3', 0=Open

Define JP1, JP3..7 & JP14..16 at the beginning of your sketch
if one or more of these solder jumpers are in place. They
can have a value of 'B' or 'C' or nothing, like this:
JP15 & JP16 can have a value of 'B' or 'D' or nothing, like this:

Platino.begin('B','C','B','B','B','B','B','D','D');

Note that:
 - if JP3=='C' then PC5 is shared between LCD backlight and RGB LED 3.
*/


#include "LiquidCrystal.h"
#include "RotaryEncoder.h"
#include "Pushbutton.h"


// LCD
#define LCD_RS  (2) /* PD2 ** D2 */
//#define LCD_RS_ALT  (23) /* PB7 ** D23 */
#define LCD_RS_ALT  (25) /* PA6 ** D25 */
#define LCD_E  (3) /* PD3 ** D3 */
//#define LCD_E_ALT  (22) /* PB6 ** D22 */
#define LCD_E_ALT  (24) /* PA7 ** D24 */
#define LCD_D4  (4) /* PD4 ** D4 */
#define LCD_D5  (5) /* PD5 ** D5 */
#define LCD_D6  (6) /* PD6 ** D6 */
#define LCD_D7  (7) /* PD7 ** D7 */


#define LED_RED  (1)
#define LED_GREEN  (2)
#define LED_BLUE  (3)


class CPlatino
{
  private:
    uint8_t _jp1;
    uint8_t _jp3;
    uint8_t _jp4;
    uint8_t _jp5;
    uint8_t _jp6;
    uint8_t _jp7;
    uint8_t _jp14;
    uint8_t _jp15;
    uint8_t _jp16;
    boolean _has_display;
    boolean _has_backlight;
    boolean _has_knob1;
    boolean _has_knob2;
    boolean _has_pushbutton1;
    boolean _has_pushbutton2;
    boolean _has_pushbutton3;
    boolean _has_pushbutton4;
    boolean _has_buzzer;
    boolean _has_led_red;
    boolean _has_led_green;
    boolean _has_led_blue;

    Pushbutton pushbutton1;
    Pushbutton pushbutton2;
    Pushbutton pushbutton3;
    Pushbutton pushbutton4;
    RotaryEncoder knob1;
    RotaryEncoder knob2;
    
    void showPin(uint8_t pin, uint8_t space=1);

  public:
    CPlatino();
    
    void init(uint8_t jp1, uint8_t jp3, uint8_t jp4, uint8_t jp5, uint8_t jp6, uint8_t jp7, uint8_t jp14, uint8_t jp15, uint8_t jp16);

    // Step 1. Call begin, f. ex.: Platino.begin(); // Use default jumper settings.
    void begin(uint8_t jp1='B', uint8_t jp3='C', uint8_t jp4='B', uint8_t jp5='B', uint8_t jp6='B', uint8_t jp7='B', uint8_t jp14='B', uint8_t jp15='D', uint8_t jp16='D')
    {
      init(jp1,jp3,jp4,jp5,jp6,jp7,jp14,jp15,jp16);
    }

    // Step 2. Call one or more hasXXX functions to activate the peripherals that are mounted on the board.
    boolean hasDisplay(uint8_t lines=2, uint8_t columns=16, boolean true_false=true, boolean splash=false);
    boolean hasBacklight(boolean true_false=true);
    boolean hasLedColor(uint8_t color=LED_GREEN, boolean true_false=true);
    boolean hasLed(boolean true_false=true) { return hasLedColor(LED_GREEN,true_false); }
    boolean hasLedRgb(boolean true_false=true);
    boolean hasBuzzer(boolean true_false=true);
    boolean hasPushbutton(uint8_t nr, boolean true_false=true);
    boolean hasKnob(uint8_t nr, boolean true_false=true);

    // Step 3. Use the peripherals.
    uint8_t pushbuttonRead(uint8_t nr, boolean clear=true);
    void pushbuttonClear(uint8_t nr);
    // Rotary encoders.
    boolean knobChanged(uint8_t nr);
    int16_t knobRead(uint8_t nr);
    void knobWrite(uint8_t nr, int16_t value);
    // LCD.
    LiquidCrystal display;
    void backlight(uint8_t value);
    // LEDs
    void led(uint8_t color, uint8_t value);
    void led(uint8_t value) { led(LED_GREEN,value); }
    void ledRgb(uint8_t red, uint8_t green, uint8_t blue) { led(LED_RED,red); led(LED_GREEN,green); led(LED_BLUE,blue); }
    // Buzzer
    void beep(unsigned int frequency, unsigned long duration);
    
    // This is called from the Timer0 ISR.
    void tick(void);
};


extern CPlatino Platino;


#endif /* __PLATINO_H__ */

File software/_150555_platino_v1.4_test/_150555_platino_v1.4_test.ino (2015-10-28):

/*
  Simple Platino test program to see if everything works as expected.

  Displays the value of rotary encoder 1. The RGB LED's color depends
  on this value. The pushbuttons influence the value too. The Buzzer
  sounds when board setup is done.
  
  Copyright (c) 2015 Elektor, www.elektor.com

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
  You should have received a copy of the GNU Lesser General
  Public License along with this library; if not, write to the
  Free Software Foundation, Inc., 59 Temple Place, Suite 330,
  Boston, MA  02111-1307  USA
*/

// Platino solder jumpers for readability.
const uint8_t jp1 = 'B'; // Buzzer
const uint8_t jp3 = 'C'; // Backlight
const uint8_t jp4 = 'B'; // S1
const uint8_t jp5 = 'B'; // S2
const uint8_t jp6 = 'B'; // S3
const uint8_t jp7 = 'B'; // S4
const uint8_t jp14 = 'B'; // LED
const uint8_t jp15 = 'D'; // LCD RS
const uint8_t jp16 = 'D'; // LCD E


void show_value(int16_t val)
{
  // Print a numerical value, right justified.
  Platino.display.setCursor(0,0);
  Platino.display.print("      ");
  Platino.display.setCursor(0,0);
  if (val>=0) Platino.display.print(' ');
  if (abs(val)<10000) Platino.display.print(' ');
  if (abs(val)<1000) Platino.display.print(' ');
  if (abs(val)<100) Platino.display.print(' ');
  if (abs(val)<10) Platino.display.print(' ');
  Platino.display.print(val);
}

void setup(void)
{
  // Configure Platino.
  Platino.begin(jp1,jp3,jp4,jp5,jp6,jp7,jp14,jp15,jp16);
  // Activate the peripherals of your board.
  Platino.hasDisplay(4,20,true,true); // 4X20 LCD, show Platino splash screen.
  Platino.hasBacklight(); // Not all LCDs have a backlight.
  Platino.hasKnob(1); // Rotary encoder (with pushbutton).
  Platino.hasPushbutton(3); // Pushbutton of rotary encoder.
  Platino.hasPushbutton(4); // Pushbutton.
  Platino.hasLedRgb(); // RGB LED.
  Platino.hasBuzzer(); // Buzzer.
  Platino.backlight(true); // Backlight on.
  Platino.ledRgb(0,0,0); // RGB LED off.
  delay(2000); // Give the user time to read the splash screen.
  Platino.display.clear(); // Clear display.
  show_value(Platino.knobRead(1)); // Print the value of rotary encoder 1.
  // Make a sound to indicate that the board is ready.
  Platino.beep(1000,100);
  delay(50);
  Platino.beep(750,100);
  delay(50);
  Platino.beep(500,100);
}

void loop(void)
{
  if (Platino.knobChanged(1)==true)
  {
    // Update the display everytime the position of enocder 1 changes.
    int16_t val = Platino.knobRead(1);
    show_value(val);
    Serial.println(val);
    // Update RGB LED.
    if (val<0) Platino.ledRgb(1,1,1); // Negative values: white.
    else if (val<10) Platino.ledRgb(0,0,0); // Less than 10: off.
    else if (val<100) Platino.ledRgb(1,0,0); // Less than 100: red.
    else if (val<1000) Platino.ledRgb(0,0,1); // Less than 1000: blue.
    else Platino.ledRgb(0,1,0); // Else: green.
  }
  if (Platino.pushbuttonRead(3)==PUSHBUTTON_DOWN)
  {
    // Pressing the encoder's pushbutton resets the encoder value.
    Platino.knobWrite(1,0);
  }
  if (Platino.pushbuttonRead(4)==PUSHBUTTON_DOWN)
  {
    // Pressing the pushbutton multiplies value by 10.
    Platino.knobWrite(1,10*Platino.knobRead(1));
  }
}

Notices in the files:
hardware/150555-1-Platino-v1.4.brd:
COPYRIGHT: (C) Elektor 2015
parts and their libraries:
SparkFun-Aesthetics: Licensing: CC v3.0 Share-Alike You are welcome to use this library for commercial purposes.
